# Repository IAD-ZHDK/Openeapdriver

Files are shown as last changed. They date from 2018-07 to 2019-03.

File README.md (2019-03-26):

# Open EAP driver
A driver and sequencer for prototyping with Dielectric Elastomers (Electroactive Polymers or EAP).

The device has both a push button activation control for EAP and an onboard sequencer for cyclic testing and creative purposes. For interactive work or for working in combination with other devices such as Arduino, the driver can be operated with a 5 volt signal from an external source. The device has an internal lipo battery with usb charging, and “hotswap” power management for uninterrupted usage during charging. The unit is based on the A50 high voltage converter from www.xppower.com (formerly EMCO). 

The Device Features:
* Internal Lipo Battery
* Rechargable over USB 
* Built in sequencer 
* Digital inputs for control with arduino 
* Push button control
* Indicator LEDS for battery charging

The maximum 5000 volt output of this device may result in electric shock if used incorrectly. Use at your own risk!

Board

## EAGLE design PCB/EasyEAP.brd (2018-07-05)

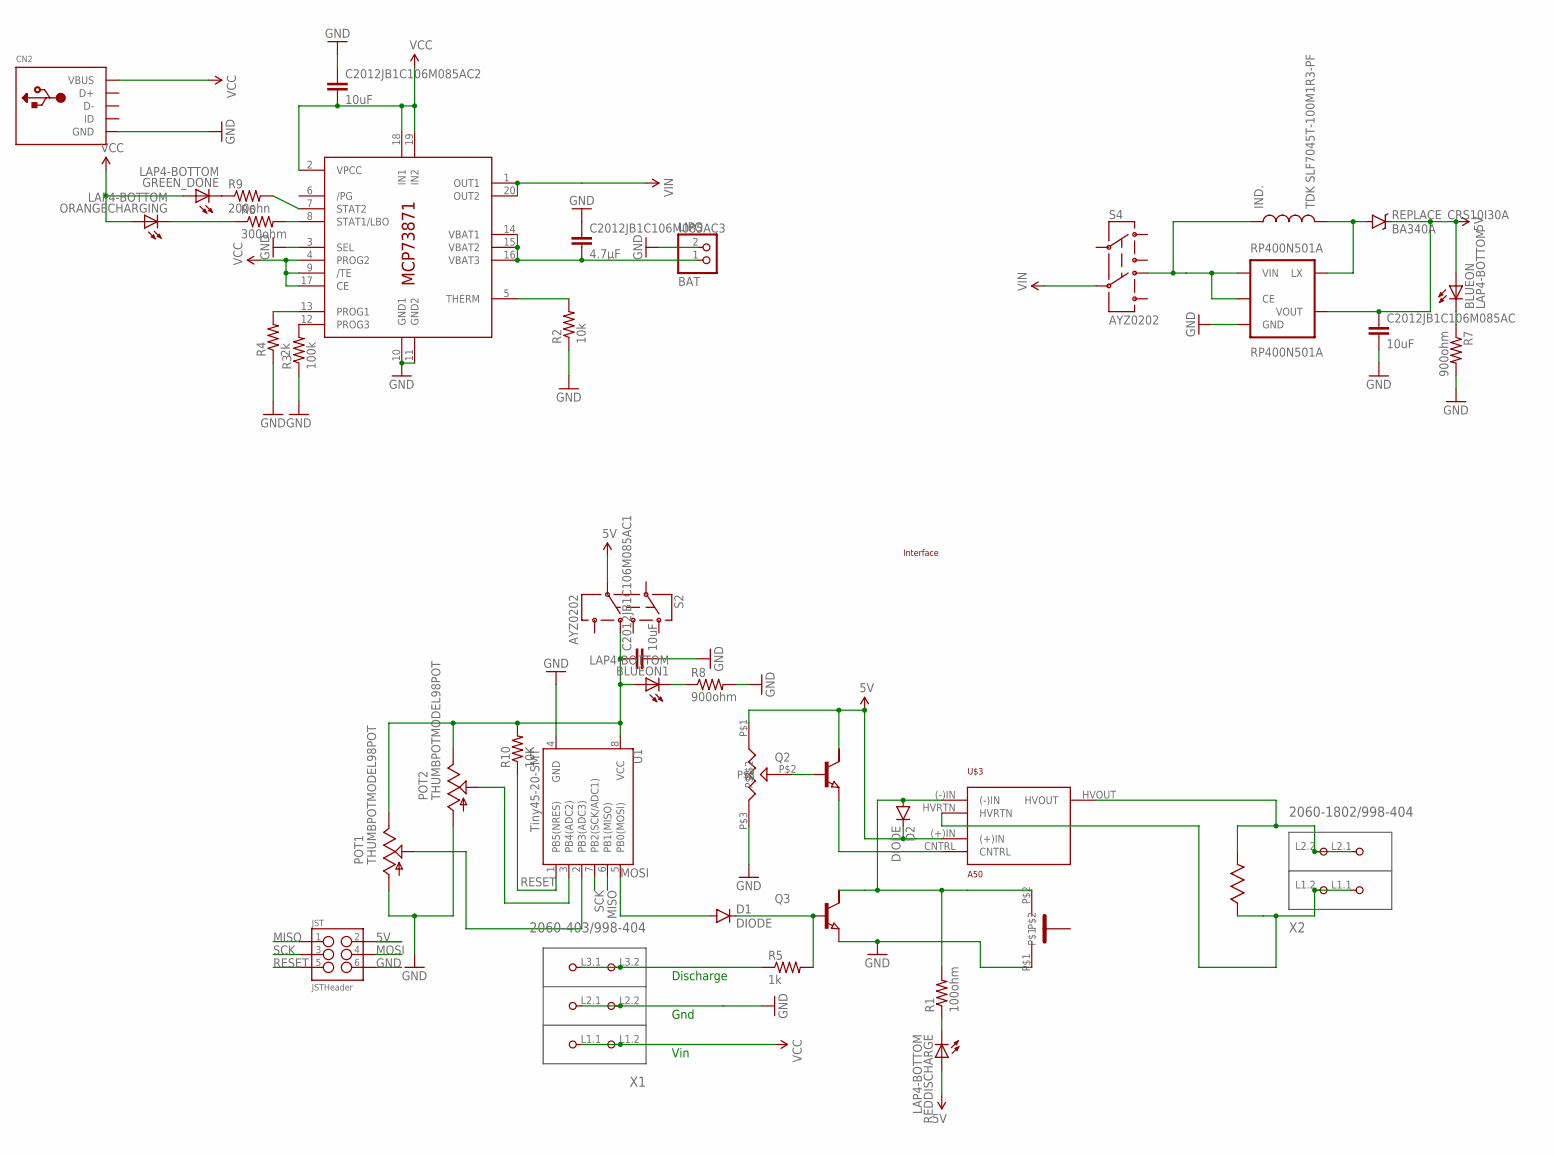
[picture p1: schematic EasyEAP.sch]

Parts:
BLUEON, BLUEON1: LAP4-BOTTOM; P47F-BOTTOM
C2012JB1C106M085AC, C2012JB1C106M085AC1, C2012JB1C106M085AC2: 10uF; 1210
C2012JB1C106M085AC3: 4.7μF; 1210
CN2: USBMINIB; USB-MINIB
D1, D2: DIODE; SMA-DIODE_ALT
GREEN_DONE: LAP4-BOTTOM; P47F-BOTTOM
IC1: MCP73871; QFN20
IND.: TDK SLF7045T-100M1R3-PF; B82462G
JST: JSTHeader; 2X3_SMD
LIPO: BAT; JST-PH-2-SMT-RA
ORANGECHARGING: LAP4-BOTTOM; P47F-BOTTOM
POT1, POT2: THUMBPOTMODEL98POT; THUMBWHEEL
Q2, Q3: NPN-TRANSISTIOR-2COLSOT89; SOT89
R1: 100ohm; 1206
R2: 10k; 1206
R3: 100k; 1206
R4: 2k; 1206
R5: 1k; 1206
R6: 300ohm; 1206
R7, R8: 900ohm; 1206
R9: 200ohn; 1206
R10: 10K; 1206
REDDISCHARGE: LAP4-BOTTOM; P47F-BOTTOM
REPLACE_CRS10I30A: BA340A; SMA-DIODE
RP400N501A: RP400N501A; SOT23-5
S2, S4: AYZ0202
U1: Tiny45-20-SMT; SO08-EIAJ
U$2: 4020SMD
U$3: A50
U$8: VISHAY
U$9: GRAYHILLPUSHBUTTON; GRAYHILLSERIES30
U$10: INTERFACE_EAP
X1: 2060-403/998-404; P-2060-403/998-404
X2: 2060-1802/998-404; P-2060-1802/998-404

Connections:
5V: BLUEON.A, C2012JB1C106M085AC.1, D2.C, JST.2, Q2.2 (C), REDDISCHARGE.A, REPLACE_CRS10I30A.C, RP400N501A.4 (VOUT), S2.5, U$3.(+)IN, U$8.P$1
5VSEQUENCE: BLUEON1.A, C2012JB1C106M085AC1.1, POT1.3 (E), POT2.3 (E), R10.2, S2.6 (4), U1.8 (VCC)
15K: POT1.2 (S), U1.2 (PB3(ADC3))
DISCHARGE: R5.1, X1.L3.1 (P3.1), X1.L3.2 (P3.2)
GND: C2012JB1C106M085AC.2, C2012JB1C106M085AC1.2, C2012JB1C106M085AC2.1, C2012JB1C106M085AC3.1, CN2.GND, IC1.3 (SEL), IC1.10 (GND1), IC1.11 (GND2), JST.6, LIPO.2 (1), POT1.1 (A), POT2.1 (A), Q3.3 (E), R2.1, R3.1, R4.1, R7.2, R8.2, RP400N501A.2 (GND), U1.4 (GND), U$8.P$3, U$9.P$1, X1.L2.1 (P2.1), X1.L2.2 (P2.2)
HVIN: U$2.P$1, U$3.HVRTN, X2.L1.1 (P1.1), X2.L1.2 (P1.2)
HVOUT: U$2.P$2, U$3.HVOUT, X2.L2.1 (P2.1), X2.L2.2 (P2.2)
MISO: JST.1, U1.6 (PB1(MISO))
MOSI: D1.A, JST.4, U1.5 (PB0(MOSI))
unnamed: IND..P$2 (2), REPLACE_CRS10I30A.A, RP400N501A.5 (LX)
unnamed: D1.C, Q3.1 (B), R5.2
unnamed: BLUEON.C, R7.1
unnamed: D2.A, Q3.2 (C), R1.2, U$3.(-)IN, U$9.P$2
unnamed: R1.1, REDDISCHARGE.C
unnamed: BLUEON1.C, R8.1
unnamed: C2012JB1C106M085AC3.2, IC1.14 (VBAT1), IC1.15 (VBAT2), IC1.16 (VBAT3), LIPO.1 (2)
unnamed: Q2.3 (E), U$3.CNTRL
unnamed: IC1.5 (THERM), R2.2
unnamed: IC1.12 (PROG3), R3.2
unnamed: Q2.1 (B), U$8.P$2
unnamed: IC1.13 (PROG1), R4.2
unnamed: POT2.2 (S), U1.3 (PB4(ADC2))
unnamed: IC1.8 (STAT1/LBO), R6.2
unnamed: ORANGECHARGING.C, R6.1
unnamed: IND..P$1 (1), RP400N501A.1 (CE), RP400N501A.3 (VIN), S4.6 (4)
unnamed: GREEN_DONE.C, R9.1
unnamed: IC1.7 (STAT2), R9.2
RESET: JST.5, R10.1, U1.1 (PB5(NRES))
SCK: JST.3, U1.7 (PB2(SCK/ADC1))
VCC: C2012JB1C106M085AC2.2, CN2.VBUS, GREEN_DONE.A, IC1.2 (VPCC), IC1.4 (PROG2), IC1.9 (/TE), IC1.17 (CE), IC1.18 (IN1), IC1.19 (IN2), ORANGECHARGING.A, X1.L1.1 (P1.1), X1.L1.2 (P1.2)
VIN: IC1.1 (OUT1), IC1.20 (OUT2), S4.5

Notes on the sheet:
Vin
Gnd
Discharge

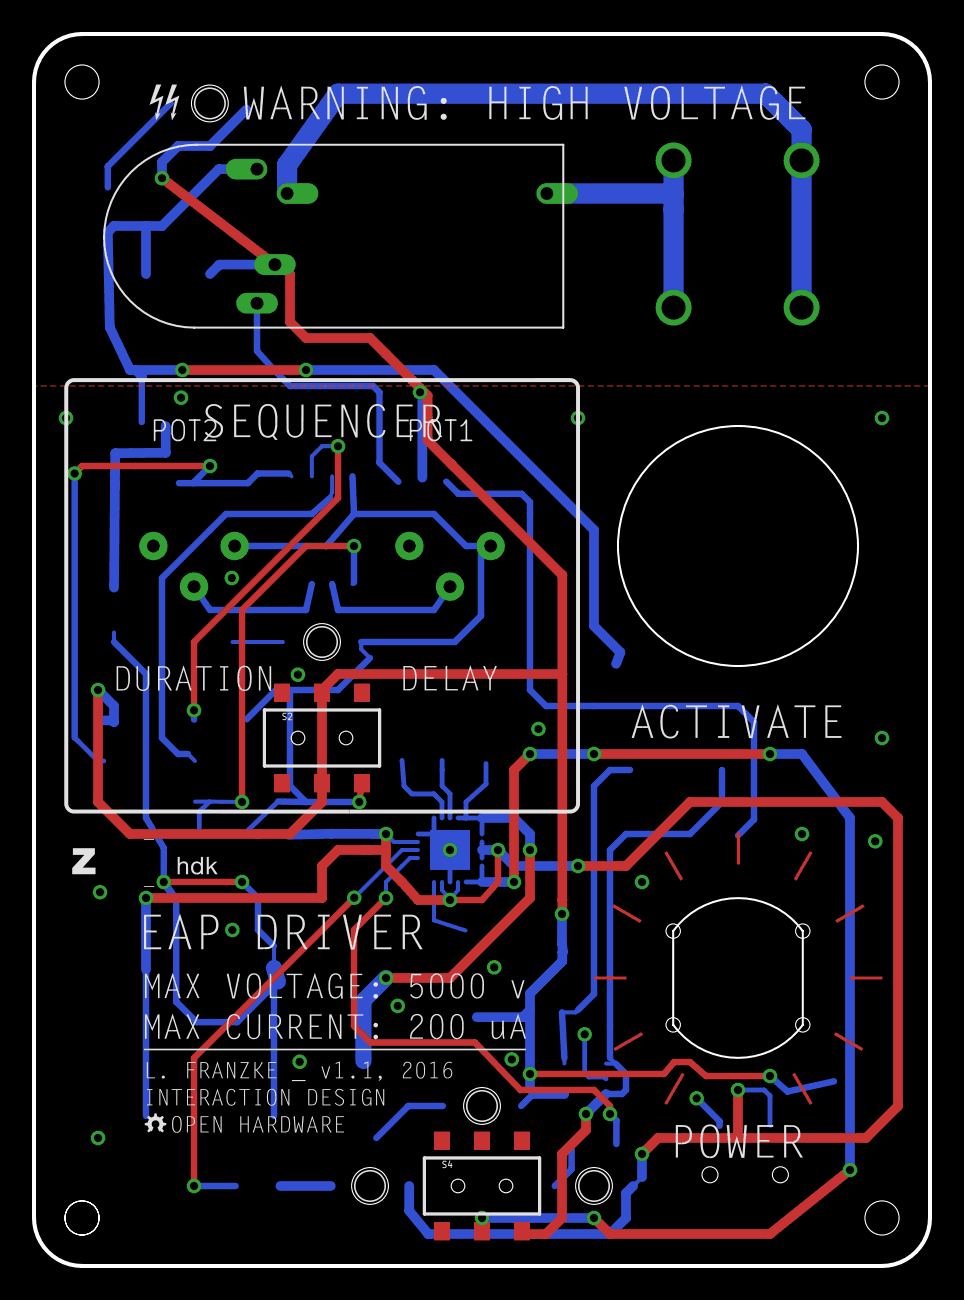
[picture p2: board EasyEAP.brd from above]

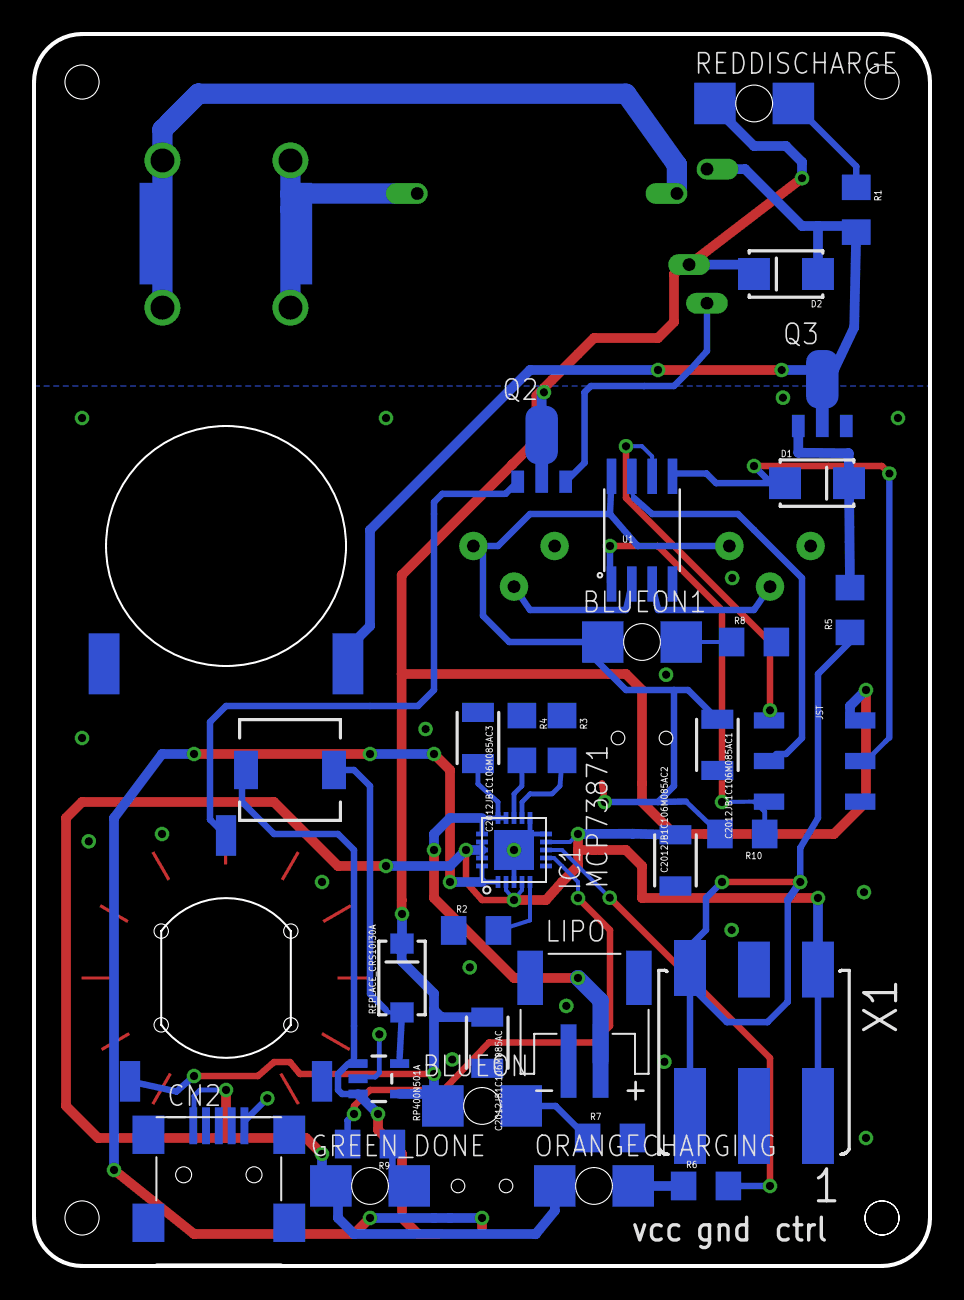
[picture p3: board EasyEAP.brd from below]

Board: 2 copper layers, 56.0 x 77.0 mm, 43 parts (33 on the bottom side), 31 nets.

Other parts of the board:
U$6: WARNING

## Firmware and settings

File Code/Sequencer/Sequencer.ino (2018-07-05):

  const int eapPin = 0;
const int ledPin = 1;
const byte potPin_1 = A3;
const byte potPin_2 = A2;
int myInterval = 2000;
int myDuration = 1500;

unsigned long milis;
unsigned long lastMili = 0;


void setup() {
  pinMode(ledPin, OUTPUT);
  pinMode(eapPin, OUTPUT);

  pinMode(potPin_1, INPUT);
  pinMode(potPin_2, INPUT);

};


void loop() {
  delay(20);

  milis = millis();
  float count = milis - lastMili;


  //sequence
  if (count <= myInterval) {
    // set sensor values
    digitalWrite(ledPin, LOW);
    digitalWrite(eapPin, LOW);
    // update values from sensors 
    myInterval = setDelayValues(potPin_1);
    myDuration = setDelayValues(potPin_2);

  } else if (count <= myInterval + myDuration) {

    digitalWrite(ledPin, HIGH);
    digitalWrite(eapPin, HIGH);

  } else {

    lastMili = milis;
  }

};

int setDelayValues(int pin) {
  int temp  = analogRead(pin);
  temp = map(temp, 0, 1023, 0, 5000); // up to 5 seconds  Serial.println(myInterval);
  return temp;
}

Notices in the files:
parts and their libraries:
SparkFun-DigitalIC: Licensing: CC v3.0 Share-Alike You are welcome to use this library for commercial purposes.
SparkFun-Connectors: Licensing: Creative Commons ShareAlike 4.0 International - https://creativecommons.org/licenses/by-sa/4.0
